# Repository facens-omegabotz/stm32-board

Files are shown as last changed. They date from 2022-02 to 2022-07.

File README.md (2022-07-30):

# stm32f446-board → KiCad Project



PCB design of a development board for the STM32f446 MCU

## Schematics



The PDF can be found [here](STM32-udemy.pdf)

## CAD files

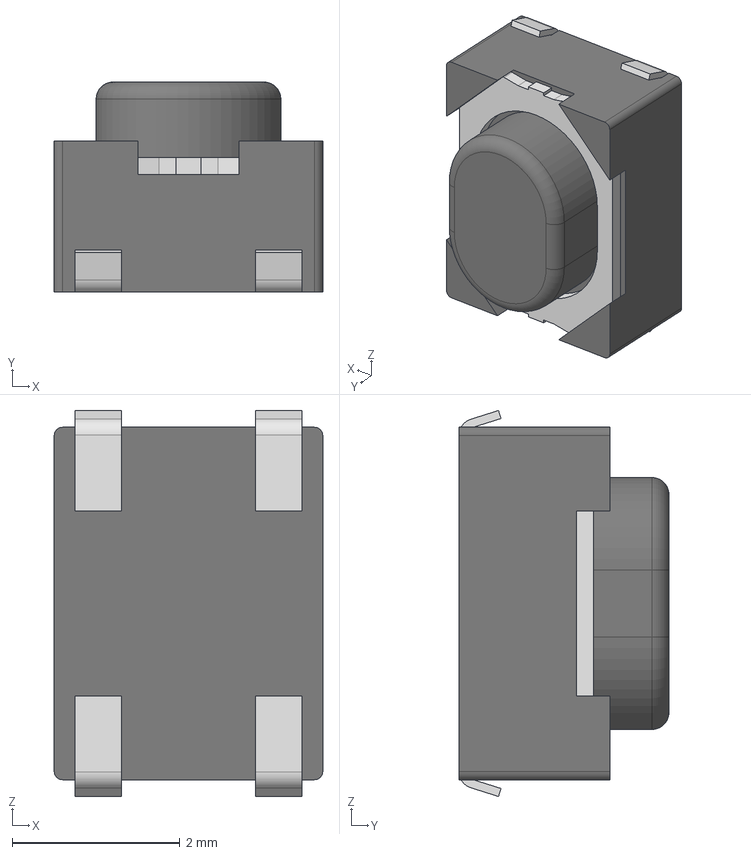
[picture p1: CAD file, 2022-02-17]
3D models/Download_STP_4341x30258x6 (rev1).stp
3.20 x 2.50 x 4.60 mm
Frame
Cover
Stem
Terminal x 4

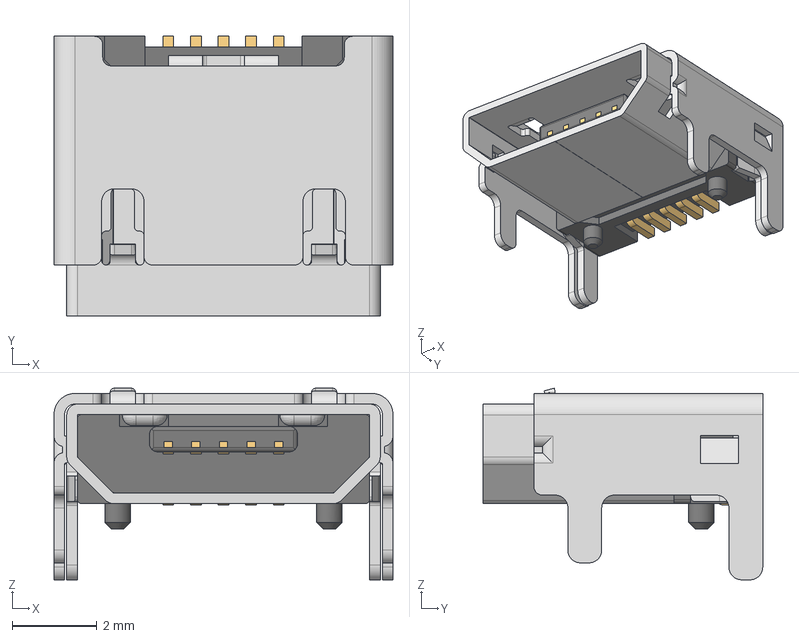
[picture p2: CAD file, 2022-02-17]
3D models/629105150521 (rev1).stp
8.00 x 6.60 x 4.52 mm
629105150521_Pin1 x 4
629105150521_Housing
629105150521_Pin2
629105150521_Shielding
629105150521_Shielding2

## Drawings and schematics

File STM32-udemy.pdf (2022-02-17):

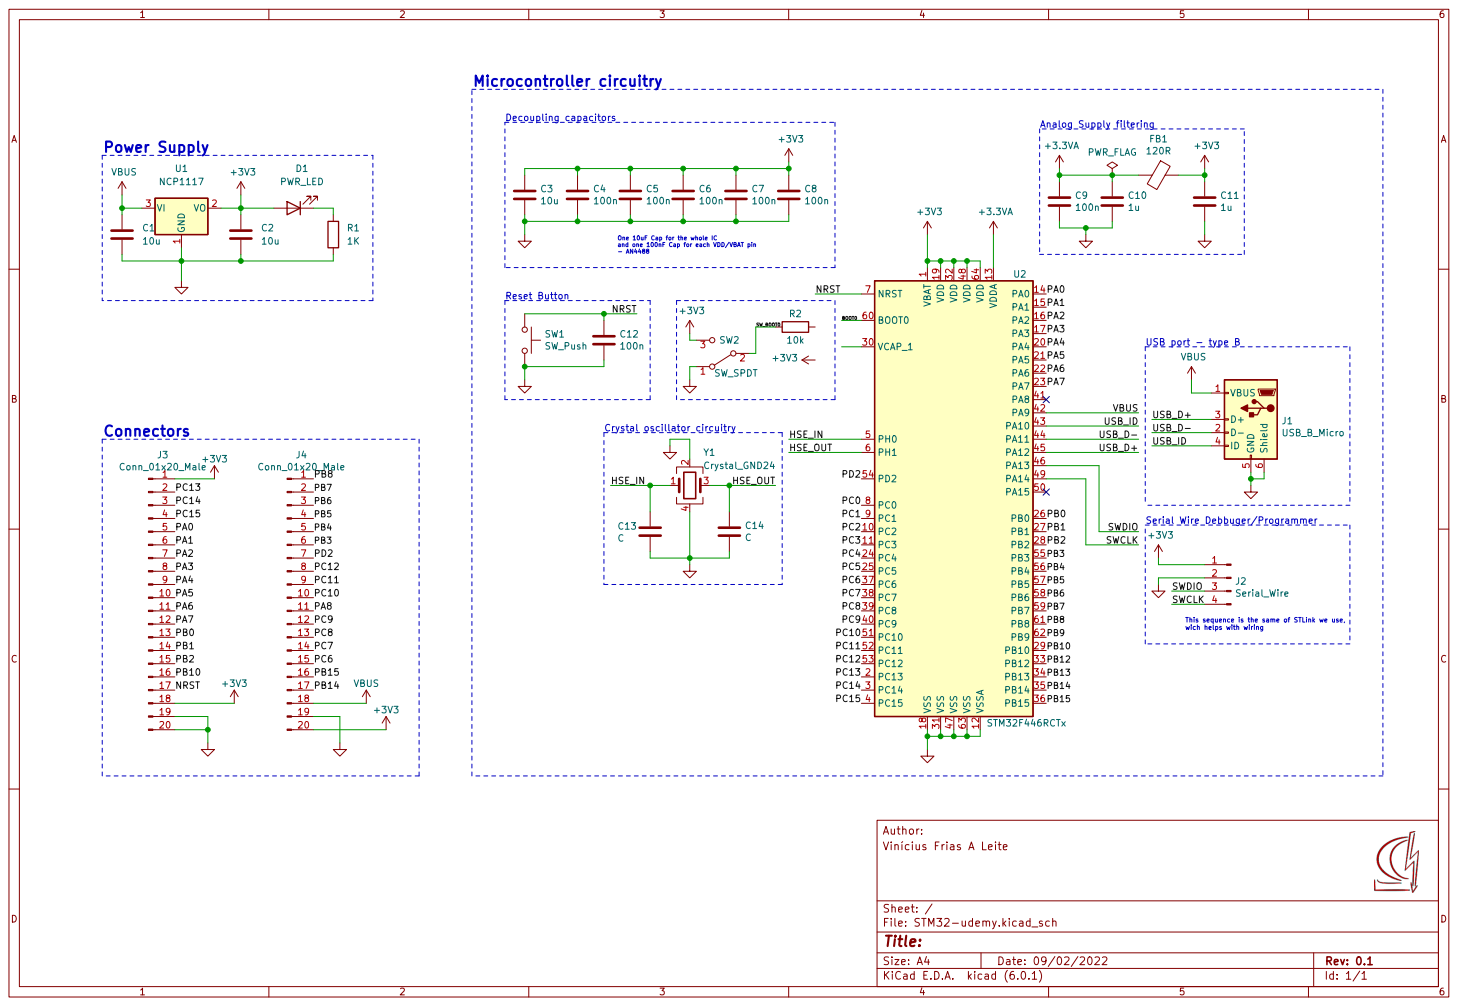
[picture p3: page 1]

Decoupling capacitors
Analog Supply filtering Reset Button

One 10uF Cap for the whole IC
and one 100nF Cap for each VDD/VBAT pin

1 PC2 10 PC3 11 VSSA 12 VDDA 13 PA0 14 PA1 15 PA2 16 PA3 17 VSS 18 VDD 19 PC13 2 PA4 20 PA5 21 PA6 22 PA7 23 PC4 24 PC5 25 PB0 26 PB1 27 PB2 28 PB10 29 PC14 3 VCAP_1 30 VSS 31 VDD 32 PB12 33 PB13 34 PB14 35 PB15 36 PC6 37 PC7 38 PC8 39 PC15 4 PC9 40 PA8 41 PA9 42 PA10 43 PA11 44 PA12 45 PA13 46 VSS 47 VDD 48 PA14 49 PH0 5 PA15 50 PC10 51 PC11 52 PC12 53 PD2 54 PB3 55 PB4 56 PB5 57 PB6 58 PB7 59 PH1 6 BOOT0 60 PB8 61 PB9 62 VSS 63 VDD 64 NRST 7 PC0 8 PC1 9 U2 STM32F446RCTx

This sequence is the same of STLink we use, wich helps with wiring Crystal oscillator circuitry

Serial Wire Debbuger/Programmer

File: STM32-udemy.kicad_sch Sheet: / þÿVinícius Frias A Leite Author:

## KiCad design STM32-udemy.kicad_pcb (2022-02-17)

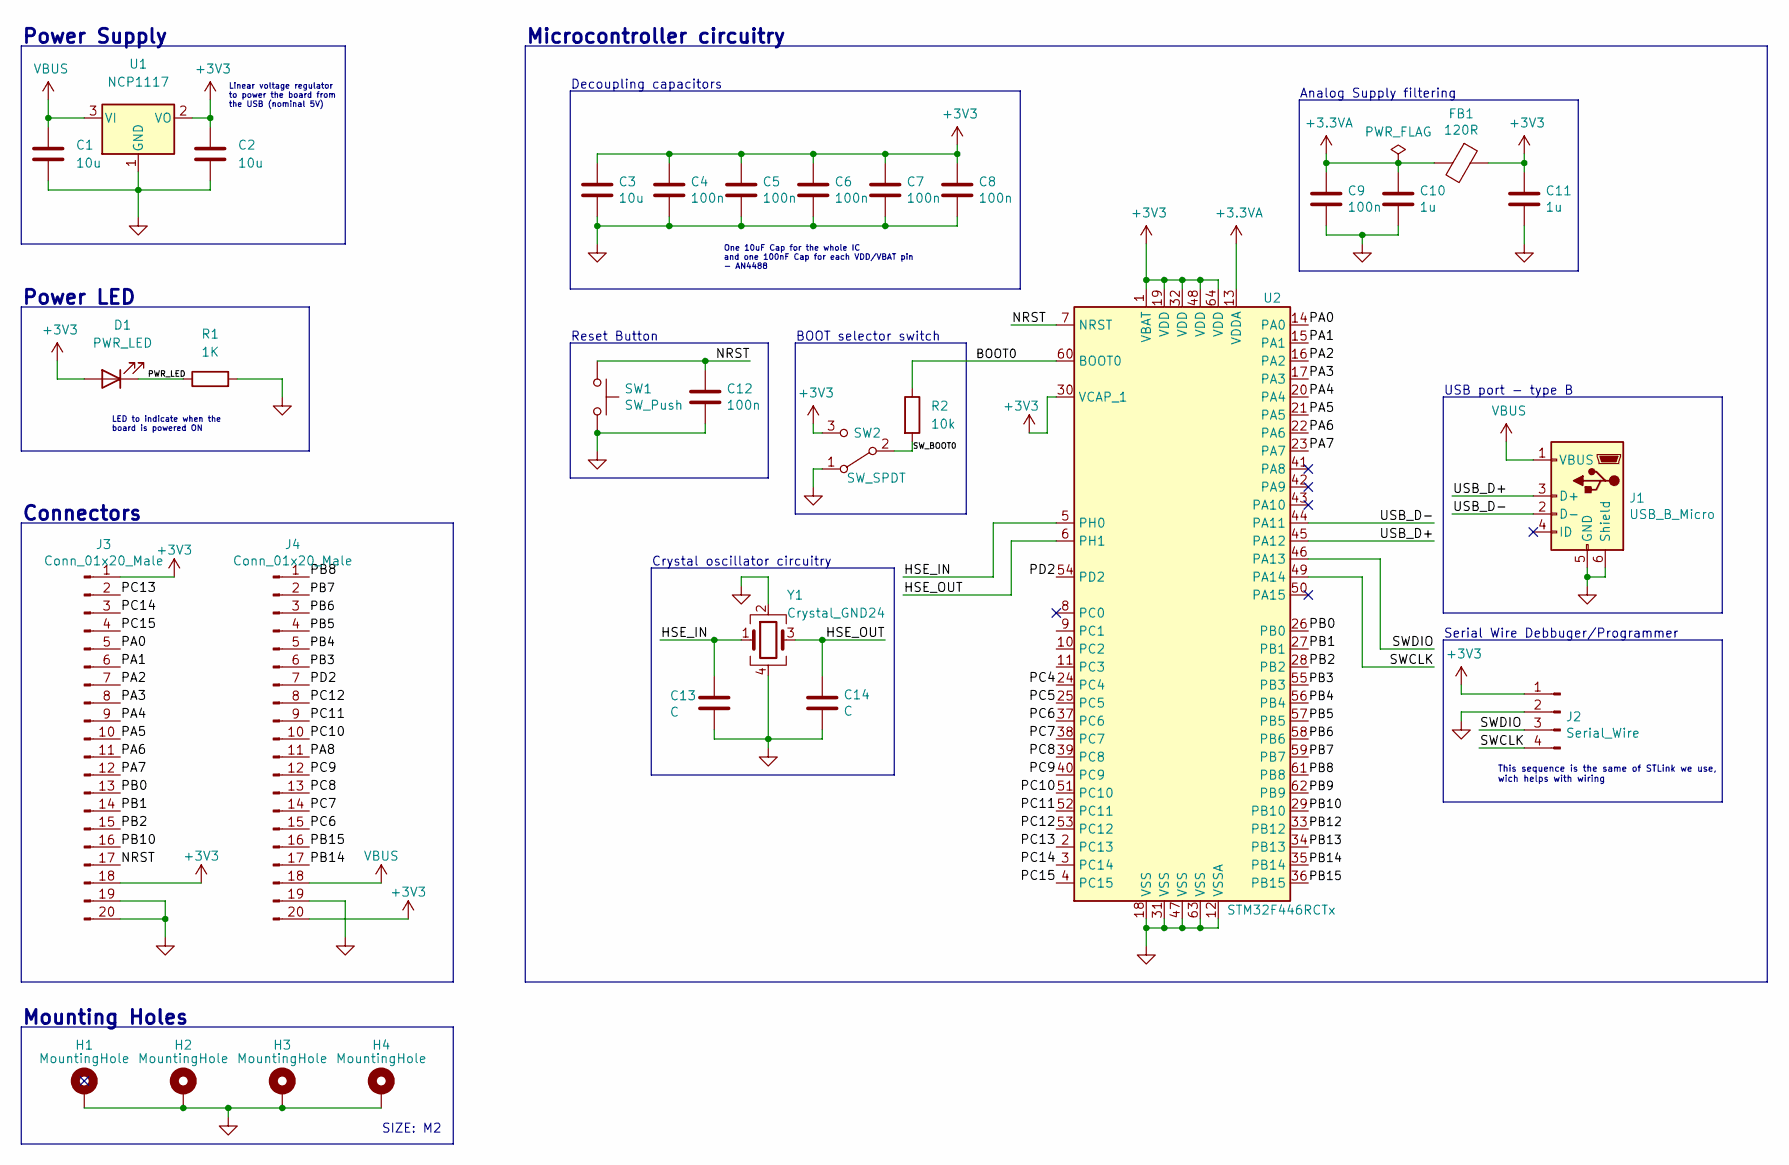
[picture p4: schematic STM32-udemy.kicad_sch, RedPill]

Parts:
C1, C2, C3: 10u; C_0805_2012Metric_Pad1.18x1.45mm_HandSolder
C4, C5, C6, C7, C8, C9, C12: 100n; C_0603_1608Metric_Pad1.08x0.95mm_HandSolder
C10, C11: 1u; C_0603_1608Metric_Pad1.08x0.95mm_HandSolder
C13, C14: C; C_0402_1005Metric_Pad0.74x0.62mm_HandSolder
D1: PWR_LED; LED_0603_1608Metric_Pad1.05x0.95mm_HandSolder
FB1: 120R; L_0603_1608Metric_Pad1.05x0.95mm_HandSolder
H1: MountingHole; MountingHole_2.2mm_M2_ISO7380_Pad
H2, H3, H4: MountingHole; MountingHole_2.2mm_M2_Pad
J1: USB_B_Micro; USB_Micro-B_Wuerth_629105150521
J2: Serial_Wire; PinHeader_1x04_P2.54mm_Vertical
J3, J4: Conn_01x20_Male; PinHeader_1x20_P2.54mm_Vertical
R1: 1K; R_0603_1608Metric_Pad0.98x0.95mm_HandSolder
R2: 10k; R_0603_1608Metric_Pad0.98x0.95mm_HandSolder
SW1: SW_Push; SW_Push_1P1T_NO_Vertical_Wuerth_434133025816
SW2: SW_SPDT; SW_SPDT_PCM12
U1: NCP1117; SOT-223-3_TabPin2
U2: STM32F446RCTx; LQFP-64_10x10mm_P0.5mm
Y1: Crystal_GND24; Crystal_SMD_3225-4Pin_3.2x2.5mm

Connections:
+3.3VA: C9.1, C10.1, FB1.2, U2.13 (VDDA)
+3V3: C2.1, C3.1, C4.1, C5.1, C6.1, C7.1, C8.1, C11.1, D1.2 (A), FB1.1, J2.1, J3.1, J3.18, J4.20, SW2.3 (C), U1.2 (VO), U2.1 (VBAT), U2.19 (VDD), U2.30 (VCAP_1), U2.32 (VDD), U2.48 (VDD), U2.64 (VDD)
/BOOT0: R2.1, U2.60 (BOOT0)
/HSE_IN: C13.1, U2.5 (PH0), Y1.1
/HSE_OUT: C14.1, U2.6 (PH1), Y1.3
/NRST: C12.1, J3.17, SW1.1, U2.7 (NRST)
/PA0: J3.5, U2.14 (PA0)
/PA1: J3.6, U2.15 (PA1)
/PA2: J3.7, U2.16 (PA2)
/PA3: J3.8, U2.17 (PA3)
/PA4: J3.9, U2.20 (PA4)
/PA5: J3.10, U2.21 (PA5)
/PA6: J3.11, U2.22 (PA6)
/PA7: J3.12, U2.23 (PA7)
/PA8: J4.11
/PB0: J3.13, U2.26 (PB0)
/PB1: J3.14, U2.27 (PB1)
/PB2: J3.15, U2.28 (PB2)
/PB3: J4.6, U2.55 (PB3)
/PB4: J4.5, U2.56 (PB4)
/PB5: J4.4, U2.57 (PB5)
/PB6: J4.3, U2.58 (PB6)
/PB7: J4.2, U2.59 (PB7)
/PB8: J4.1, U2.61 (PB8)
/PB9: U2.62 (PB9)
/PB10: J3.16, U2.29 (PB10)
/PB12: U2.33 (PB12)
/PB13: U2.34 (PB13)
/PB14: J4.17, U2.35 (PB14)
/PB15: J4.16, U2.36 (PB15)
/PC0: U2.8 (PC0)
/PC1: U2.9 (PC1)
/PC2: U2.10 (PC2)
/PC3: U2.11 (PC3)
/PC4: U2.24 (PC4)
/PC5: U2.25 (PC5)
/PC6: J4.15, U2.37 (PC6)
/PC7: J4.14, U2.38 (PC7)
/PC8: J4.13, U2.39 (PC8)
/PC9: J4.12, U2.40 (PC9)
/PC10: J4.10, U2.51 (PC10)
/PC11: J4.9, U2.52 (PC11)
/PC12: J4.8, U2.53 (PC12)
/PC13: J3.2, U2.2 (PC13)
/PC14: J3.3, U2.3 (PC14)
/PC15: J3.4, U2.4 (PC15)
/PD2: J4.7, U2.54 (PD2)
/PWR_LED: D1.1 (K), R1.1
/SWCLK: J2.4, U2.49 (PA14)
/SWDIO: J2.3, U2.46 (PA13)
/SW_BOOT0: R2.2, SW2.2 (B)
/USB_D+: J1.3 (D+), U2.45 (PA12)
/USB_D-: J1.2 (D-), U2.44 (PA11)
GND: C1.2, C2.2, C3.2, C4.2, C5.2, C6.2, C7.2, C8.2, C9.2, C10.2, C11.2, C12.2, C13.2, C14.2, H1.1, H2.1, H3.1, H4.1, J1.5 (GND), J1.6 (Shield), J2.2, J3.19, J3.20, J4.19, R1.2, SW1.2, SW2.1 (A), U1.1 (GND), U2.12 (VSSA), U2.18 (VSS), U2.31 (VSS), U2.47 (VSS), U2.63 (VSS), Y1.2, Y1.4
VBUS: C1.1, J1.1 (VBUS), J4.18, U1.3 (VI)

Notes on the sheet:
Mounting Holes
Connectors
Crystal oscillator circuitry
Reset Button
LED to indicate when the board is powered ON
SIZE: M2
Microcontroller circuitry
This sequence is the same of STLink we use, wich helps with wiring
Power Supply
Power LED
Linear voltage regulator to power the board from the USB (nominal 5V)
USB port - type B
Analog Supply filtering
BOOT selector switch
Serial Wire Debbuger/Programmer
Decoupling capacitors
One 10uF Cap for the whole IC and one 100nF Cap for each VDD/VBAT pin - AN4488

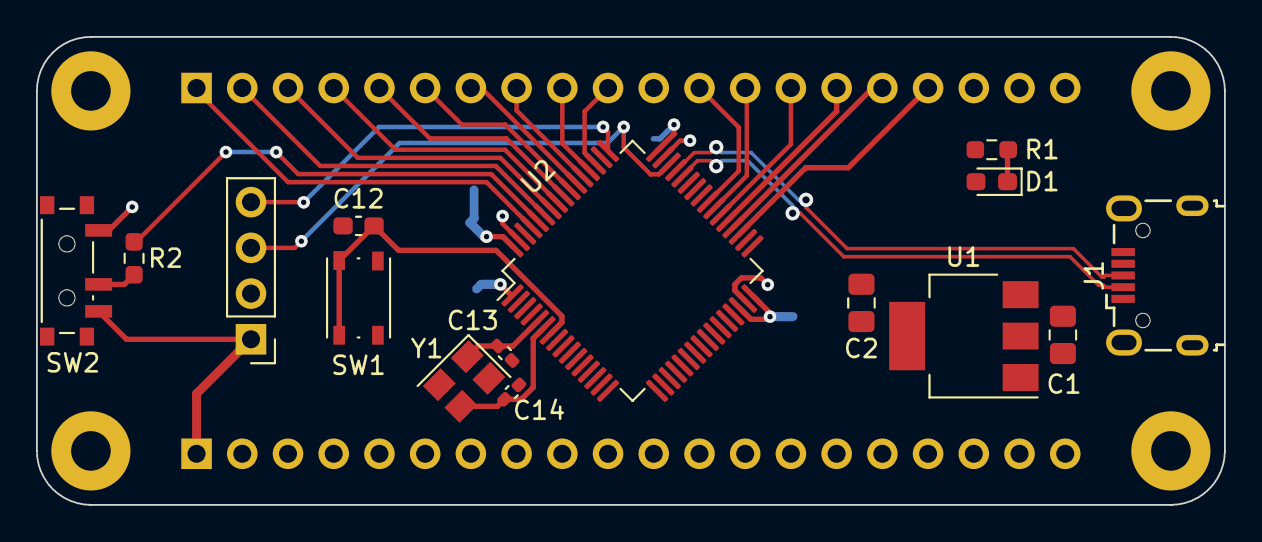
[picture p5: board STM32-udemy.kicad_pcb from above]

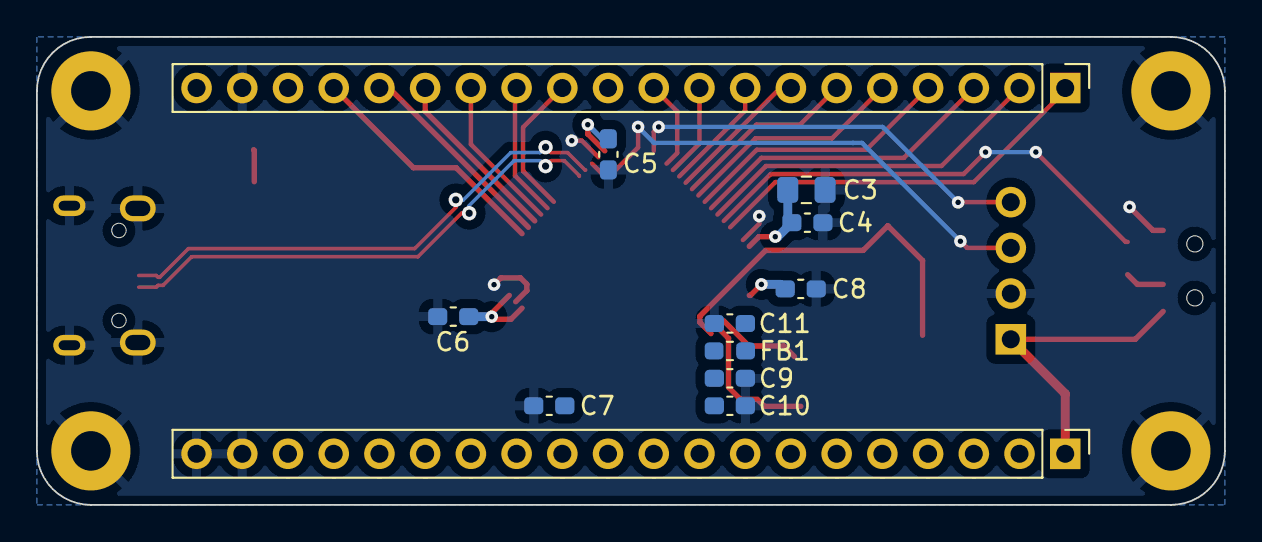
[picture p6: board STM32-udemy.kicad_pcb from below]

Board: 2 copper layers, 66.0 x 26.0 mm, 31 parts (12 on the bottom side), 45 nets.

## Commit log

2022-02-07 Add Schematic file
    First local commit, adding schematic file with:
    - STM32F446RCT6 MCU
    - Decoupling capacitors
    [STM32-udemy.sch]
2022-02-07 Add pcb and project files
    [STM32-udemy.kicad_pcb]
2022-02-08 Add USB and Serial Wire schematic
    [STM32-udemy.sch]
2022-02-08 Add KiCAD V6 files
    [STM32-udemy.kicad_sch, STM32-udemy.sch]
2022-02-17 Schematic and basic layout
    [629105150521 (rev1).stp, Download_STP_4341x30258x6 (rev1).stp, STM32-udemy.kicad_pcb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]
